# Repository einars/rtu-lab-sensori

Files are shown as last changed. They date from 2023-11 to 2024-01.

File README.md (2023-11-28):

RTU plotera sensoru knibinātājs
===============================

Experimental school stuff. You probably don't need this.

RTU CECA0.

Šobrīd te ir kods (breadboarda) simulācijai, lai sekotu plotera statusam un
indicētu sarkanu-dzeltenu-zaļu, atkarībā no ploterim piejūgtajiem induktīvajiem
strāvas sensoriem. Tie seko līdzi, vai darbojas nosūcējs un vai plotera lāzeris
darbojas. 

Gala rezultātā būs ērti pārskatāms neinvazīvs indikators, kurš samazinās
iespēju darbināt ploteri ar izslēgtu nosūcēju, un indicēs, ka ploterēšanas
darbi ir beigušies.

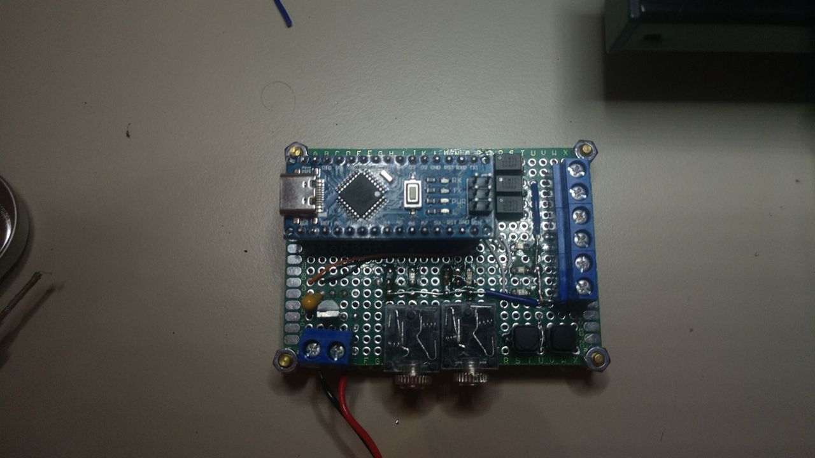
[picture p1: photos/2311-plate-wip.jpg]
Platīte


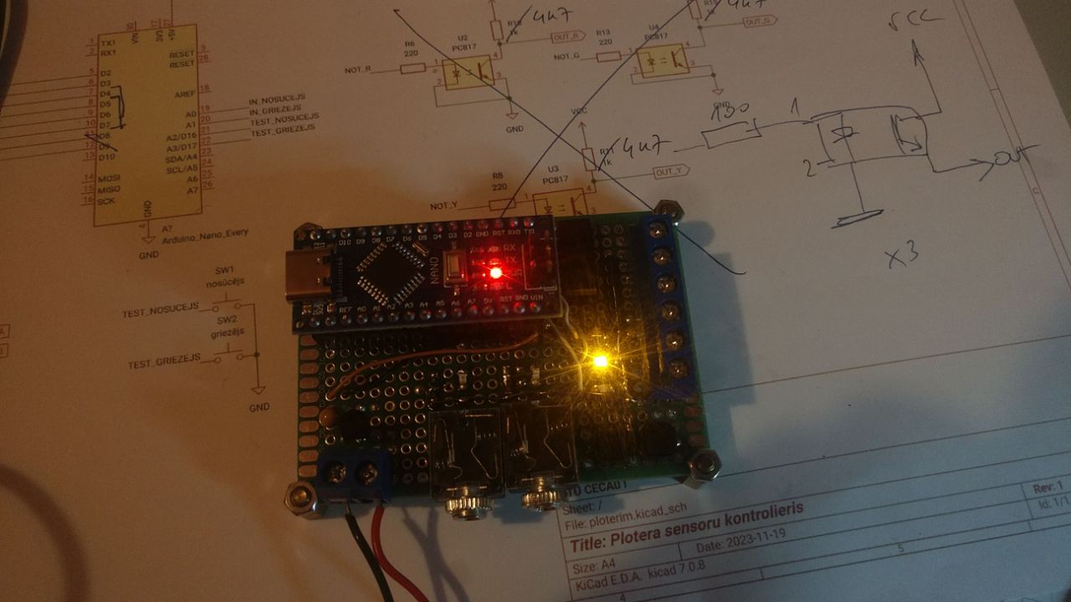
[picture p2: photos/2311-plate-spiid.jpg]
Platīte spīd


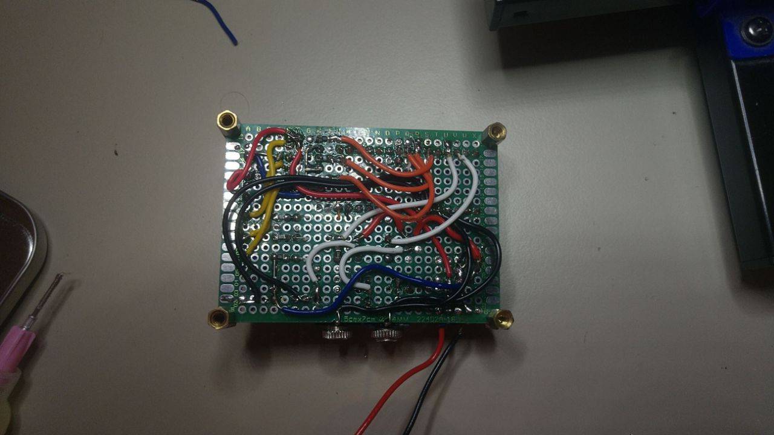
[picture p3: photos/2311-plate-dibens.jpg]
Platīte no apakšas izskatās pēc miskastes


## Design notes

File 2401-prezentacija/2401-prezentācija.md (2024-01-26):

---
marp: true
theme: olive
paginate: true
---

# Neinvazīva sistēma lāzergriezēja monitorēšanai

Einārs Lielmanis, 2024

https://github.com/einars/rtu-lab-sensori

---
# Arhitektūra

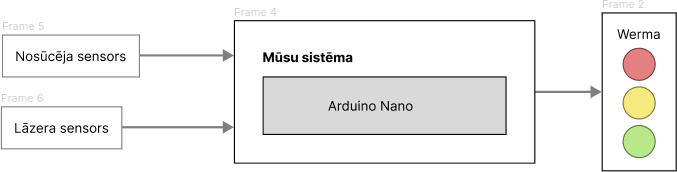
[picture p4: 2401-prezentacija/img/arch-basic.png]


---

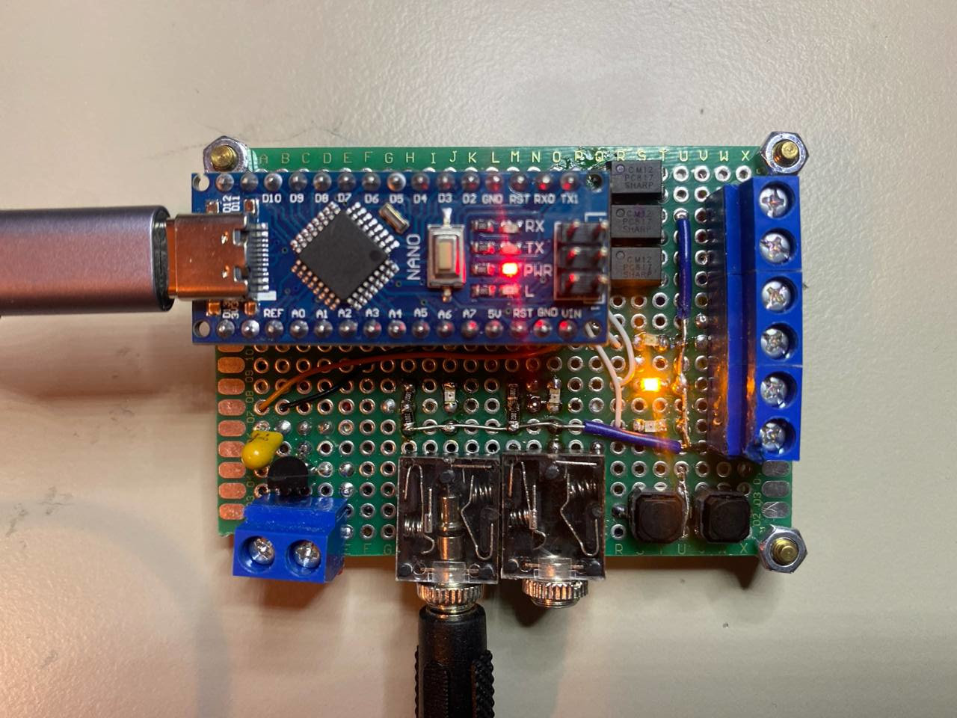
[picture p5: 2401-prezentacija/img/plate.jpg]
bg


---
# Shēma

https://github.com/einars/rtu-lab-sensori/tree/main/kicad/ploterim

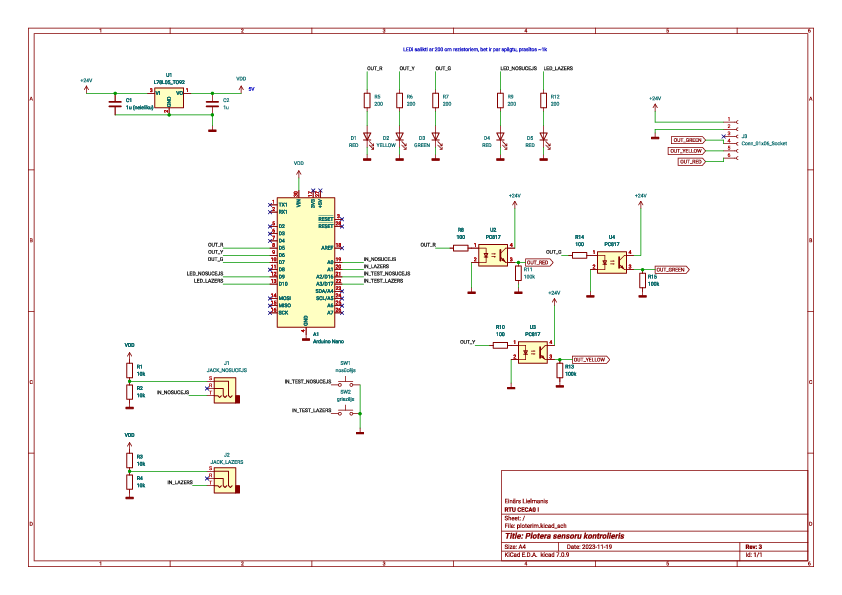
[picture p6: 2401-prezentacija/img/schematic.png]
whitesm


---

# Arhitektūra ar testiem

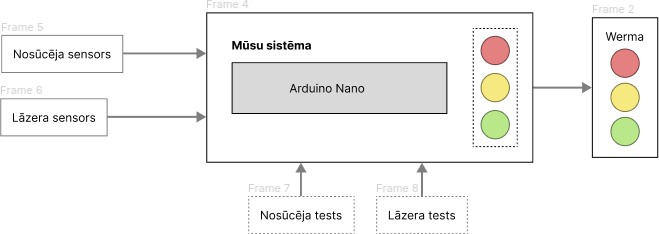
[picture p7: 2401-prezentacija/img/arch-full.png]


---

# Testi

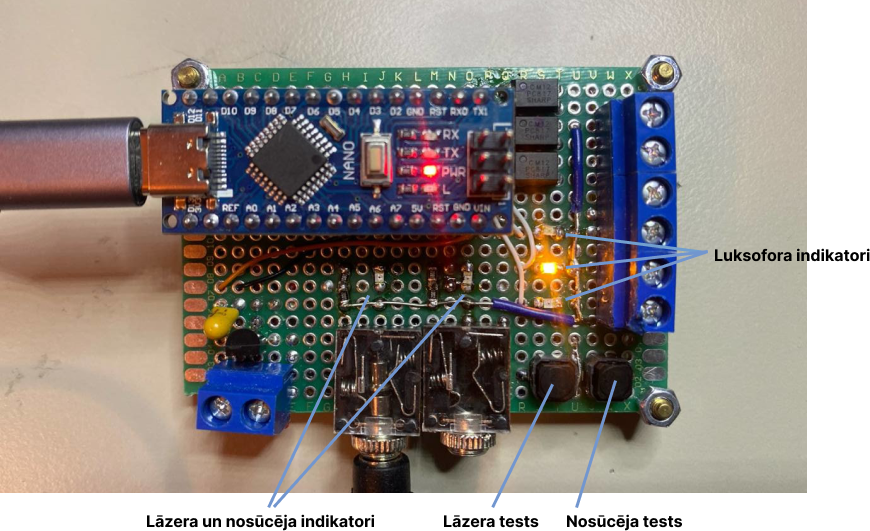
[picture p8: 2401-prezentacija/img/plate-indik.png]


---

# Barošana

- USB
- 24V 

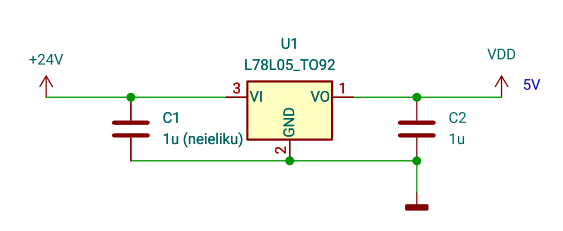
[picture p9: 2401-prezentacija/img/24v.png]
  

- abus kopā nevajadzētu

---

# Ievade

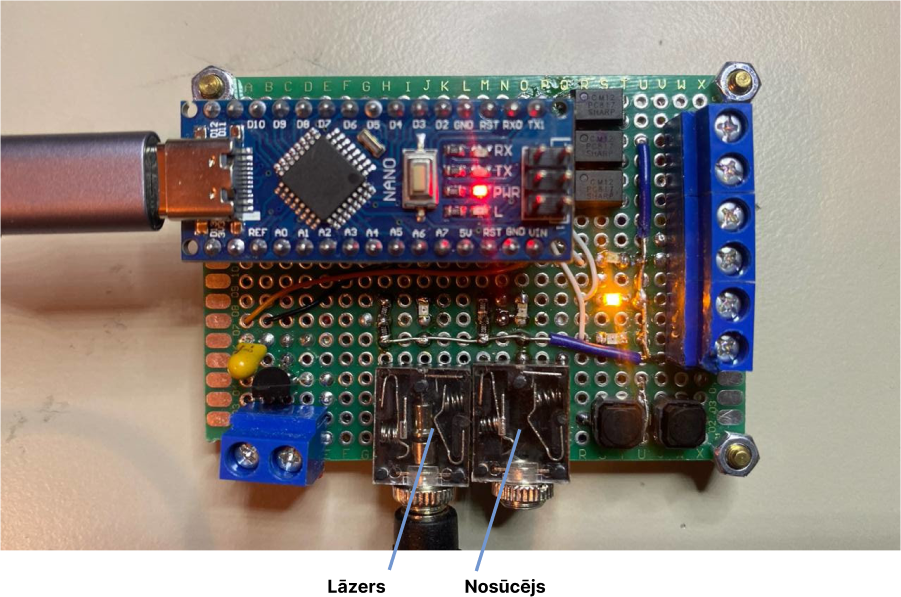
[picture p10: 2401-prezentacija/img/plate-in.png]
  

---

# Ievade

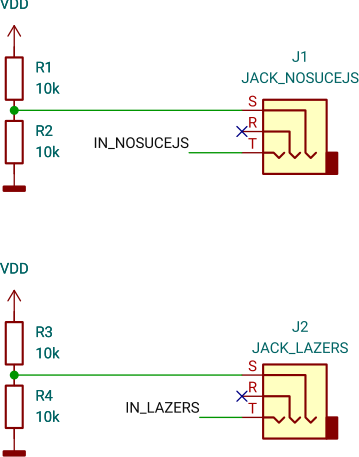
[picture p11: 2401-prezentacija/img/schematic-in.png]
  

---

# Izvade

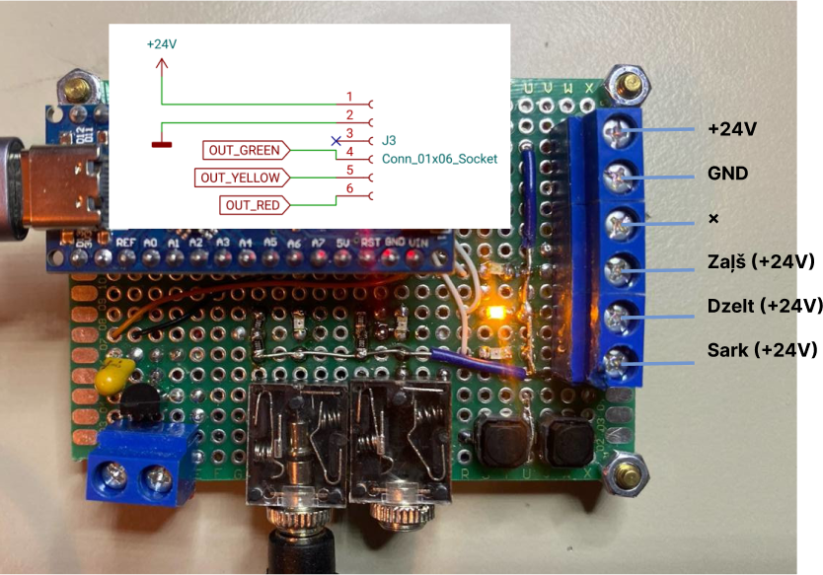
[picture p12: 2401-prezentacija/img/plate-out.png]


---

# Kods

## Ploteris

Steitmašīna: Idle → Printing → Cooldown → Finished (→ Printing)

Cooldown periods definēts kodā.

## Nosūcējs

Steitmašīna On → Off (→ On)

Raugoties uz šiem stāvokļiem, algoritms izdomā, cik veselīgu luksoforu attēlot.

---

```C
    Health h = Health::Ok;

    if ( ! n.nosuce_on) {
        h = Health::ErrNosucejs;
        if (n.plotter != Plotter::Idle && n.plotter != Plotter::Finished)
            h = Health::ErrNosucejsEmergency;
    } else
        if (n.plotter != Plotter::Idle && n.plotter != Plotter::Finished)
            h = Health::Working;

    switch (h)
    case Health::Ok:
        if (n.plotter == Plotter::Finished) leds(0, 0, 1);
        else leds(0, 0, 0);

    case Health::ErrNosucejs:
        leds(0, 1, 0);

    case Health::ErrNosucejsEmergency:
        leds(1, 1, 0);

    case Health::Working:
        leds(1, 0, 0);
```

---

# Praktiski

- Testi ļāva darboties bez pašas iekārtas

- analogie lasītāji praksē šobrīd nestrādā: kaut kur, lodējot, kļūme un, pieslēdzot vienu, abos nolasās miskaste

---

# Challenges

- smd ir lieliski, through-hole — ķēpa
- maketplates savienojumi ir elle

# Next

- Uzmaketēt īstu platīti
- Izveidot kastīti
- Iedzīvināt dzīvē

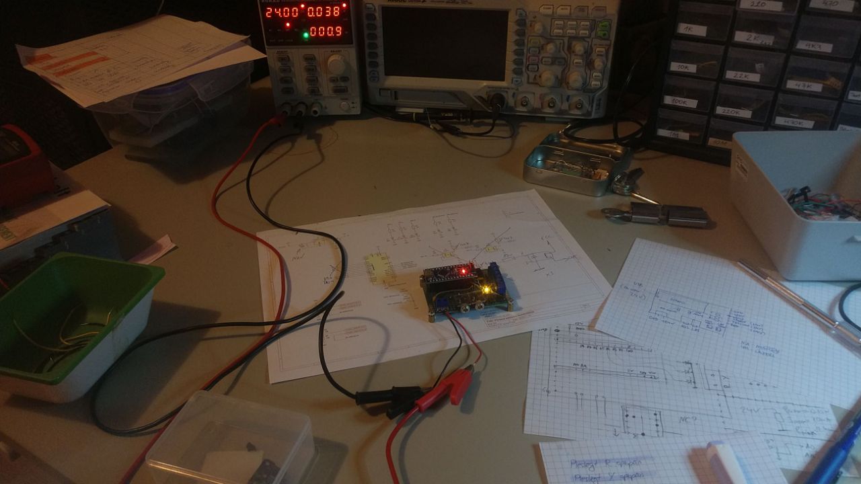
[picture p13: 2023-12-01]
photos/2311-plate-galds.jpg

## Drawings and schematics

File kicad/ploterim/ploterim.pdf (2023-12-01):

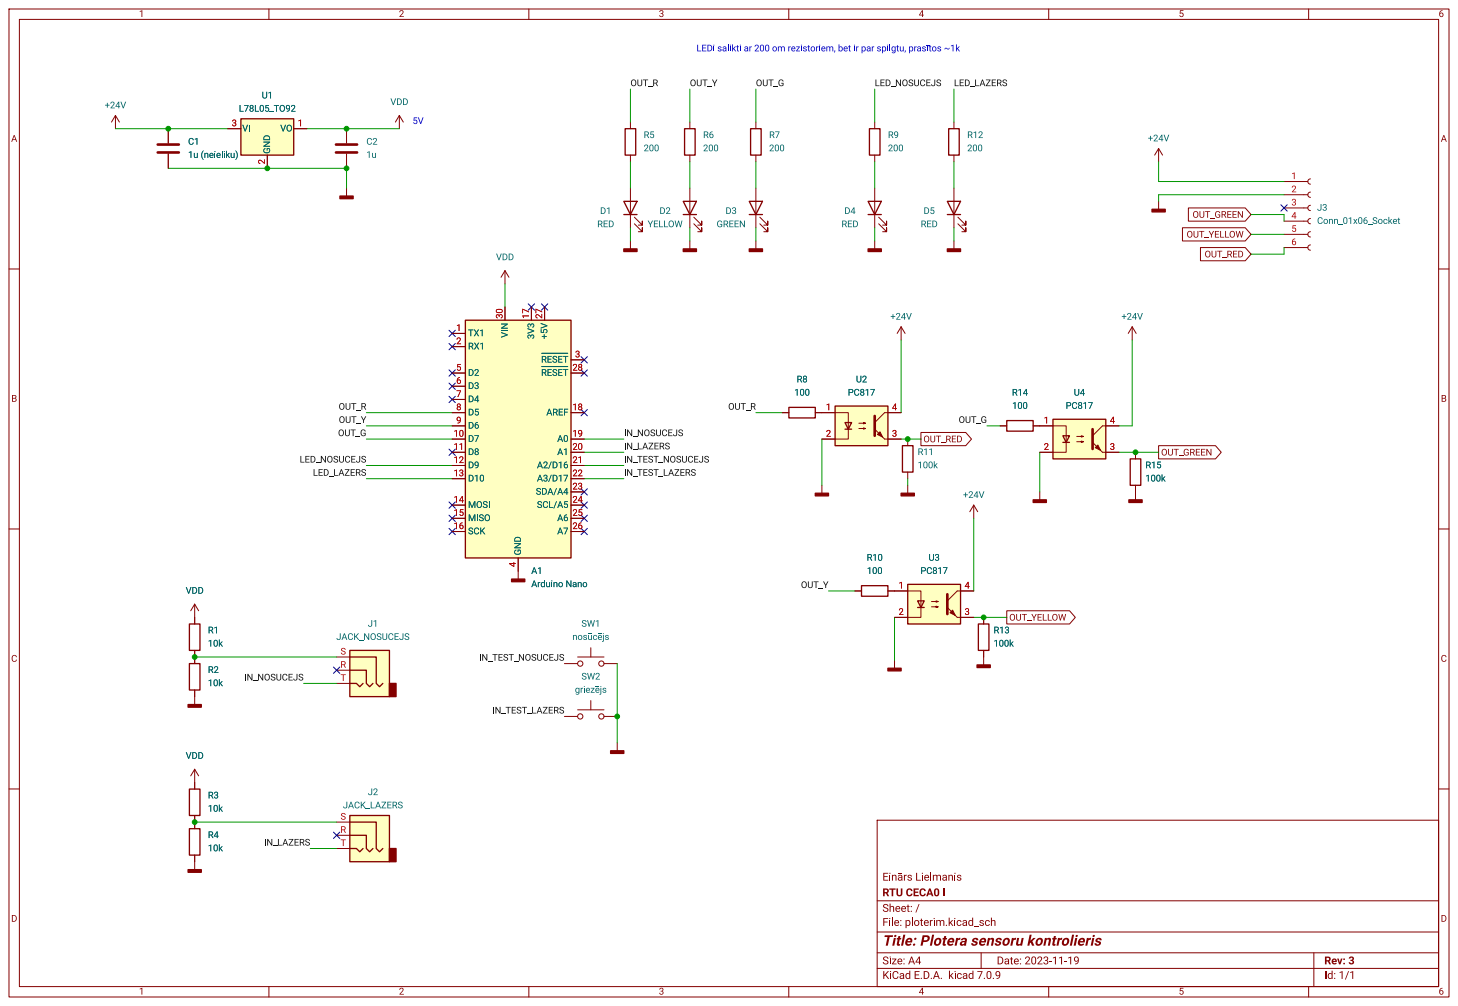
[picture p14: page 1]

LEDisalikti ar 200 om rezistoriem, bet ir par spilgtu, þÿpras+tos ~1k 5V C1

File: ploterim.kicad_sch Sheet: / RTUCECA0I þÿEinrs Lielmanis VDD

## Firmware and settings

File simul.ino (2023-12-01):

#include "Arduino.h"

const int out_red = 5;
const int out_yellow = 6;
const int out_green = 7;

const int in_nosuce = A0;
const int in_plotter = A1;

const int test_nosuce_inv = 16;
const int test_plotter_inv = 17;

const int debug_nosuce = 10;
const int debug_plotter = 9;

enum Plotter {
    Idle,
    Printing,
    Cooldown,
    Finished,
};

enum Health {
    Ok,
    ErrNosucejs,
    ErrNosucejsEmergency,
    Working,
};

// cik sekundes ilgs ir kūldauns pēc lāzera beigām, lai uzskatītu, ka printeris ir beidzis darbu.
const unsigned Cooldown_s     digitalWrite(out_red, r ? HIGH : LOW);

    digitalWrite(out_yellow, y ? HIGH : LOW);

    digitalWrite(out_green, g ? HIGH : LOW);
}
= 5;

struct state_t {
    Plotter plotter = Plotter::Idle;
    unsigned long t_cooldown_end = 0;
    bool nosuce_on = false;
    bool plotter_on = false;
};

void leds(int r, int y, int g) {
    digitalWrite(out_red, r ? HIGH : LOW);

    digitalWrite(out_yellow, y ? HIGH : LOW);

    digitalWrite(out_green, g ? HIGH : LOW);
}

void blink_hello () {
    leds(1, 1, 1);
    delay(500);
}

void get_state (state_t& s) {
    // todo: debounce

    s.plotter_on = ! digitalRead(test_plotter_inv);

    unsigned long t = millis() / 1000; // operējam ar sekundēm

    if (s.plotter == Plotter::Printing && ! s.plotter_on) {
        s.plotter = Plotter::Cooldown;
        s.t_cooldown_end = t + Cooldown_s;
    }
    if (s.plotter_on) {
        s.plotter = Plotter::Printing;
    }

    // millis() overflowo pēc 50 dienām: ja plotera indikators būs ieslēgts 50
    // dienas pēc kārtas, tad 50. dienā tas var palaist garām vienu
    // Cooldown => Finished pāreju un palikt nebeidzamā cooldownā līdz nākamajai
    // drukai.
    //
    if (s.plotter == Plotter::Cooldown && t > s.t_cooldown_end) {
        s.plotter = Plotter::Finished;
    }

    s.nosuce_on = ! digitalRead(test_nosuce_inv);

    if ( ! s.nosuce_on && s.plotter == Plotter::Finished) {
        // nosūce izslēgta, atgriežamies atkal sākuma pozīcijā, resetojam printeri uz Idle
        // (mazliet atšķiras indikācijas, atkarībā no tā, vai printeris ir Idle, vai Finished —
        // idle nav nekā jāindicē, Finished tiek spīdināts)
        s.plotter = Plotter::Idle;
    }
}

state_t n;

void setup () {

    // indikatori + optopāri
    pinMode(out_red, OUTPUT);
    pinMode(out_yellow, OUTPUT);
    pinMode(out_green, OUTPUT);

    pinMode(in_nosuce, INPUT);
    pinMode(in_plotter, INPUT);

    pinMode(test_nosuce_inv, INPUT_PULLUP);
    pinMode(test_plotter_inv, INPUT_PULLUP);

    pinMode(debug_plotter, OUTPUT);
    pinMode(debug_nosuce, OUTPUT);


    leds(0, 0, 0);

    // blink_hello();

    Serial.begin(115200);

}

void loop_test () {
    // leds(digitalRead(test_nosuce_inv), digitalRead(test_plotter_inv), millis() % 1000 > 200);
    // digitalWrite(debug_nosuce,  ! digitalRead(test_nosuce_inv));
    // digitalWrite(debug_plotter, ! digitalRead(test_plotter_inv));

    const int d = 1000;
    leds(1, 1, 0);
    delay(d);
    leds(0, 1, 1);
    delay(d);
    leds(1, 0, 1);
    delay(d);
}

void loop_sim () {

    get_state(n);

    Health h = Health::Ok;

    // debugi
    digitalWrite(debug_nosuce, n.nosuce_on);
    digitalWrite(debug_plotter, n.plotter_on);

    if ( ! n.nosuce_on) {

        h = ErrNosucejs;

        if (n.plotter != Plotter::Idle && n.plotter != Plotter::Finished) {
            h = ErrNosucejsEmergency;
        }
    } else {
        if (n.plotter != Plotter::Idle && n.plotter != Plotter::Finished) {
            h = Health::Working;
        }
    }

    switch (h) {
    case Health::Ok:
        if (n.plotter == Plotter::Finished) {
            leds(0, 0, 1);
        } else {
            leds(0, 0, 0);
        }
        break;
    case Health::ErrNosucejs:
        leds(0, 1, 0);
        break;
    case Health::ErrNosucejsEmergency:
        if ((millis() % 1000) < 200) {
            leds(1, 0, 0);
        } else {
            leds(1, 1, 0);
        }
        break;
    case Health::Working:
        leds(1, 0, 0);
        break;
    }

    Serial.print("NOS: ");
    Serial.print(analogRead(in_nosuce));

    Serial.print(" LAZ: ");
    Serial.print(analogRead(in_plotter));
    Serial.print("\n");

    delay(100);


}

void loop () {
    // loop_sim();
    loop_test();
}

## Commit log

2023-11-12 Properāka mirkšķināšana — lai sarkanais migā
2023-11-12 laser_off_at_ms -> t_cooldown_ends
2023-11-19 Schēma wip
    [ploterim.kicad_pcb, ploterim.kicad_sch]
2023-11-21 WIP testing leds
2023-11-28 Viss daudz glītāk
    [ploterim.kicad_sch]
2023-12-01 rel3: pull-down rezistori pie optokapleriem
    [ploterim.kicad_sch]
